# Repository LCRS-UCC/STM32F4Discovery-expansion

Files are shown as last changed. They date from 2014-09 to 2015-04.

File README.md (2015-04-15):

Placa de expansión para el kit STM32F4-Discovery
================================================

Esta es una placa con el propósito de agregar muchos periféricos para poder utilizar el kit de evaluación STM32F4-Discovery.

Periféricos:

* Ethernet
* Mirco-SD
* RGB
* Potenciómetro
* puerto serie con conversor USB
* VGA
* 4 pulsadores 
* 8 leds

placa

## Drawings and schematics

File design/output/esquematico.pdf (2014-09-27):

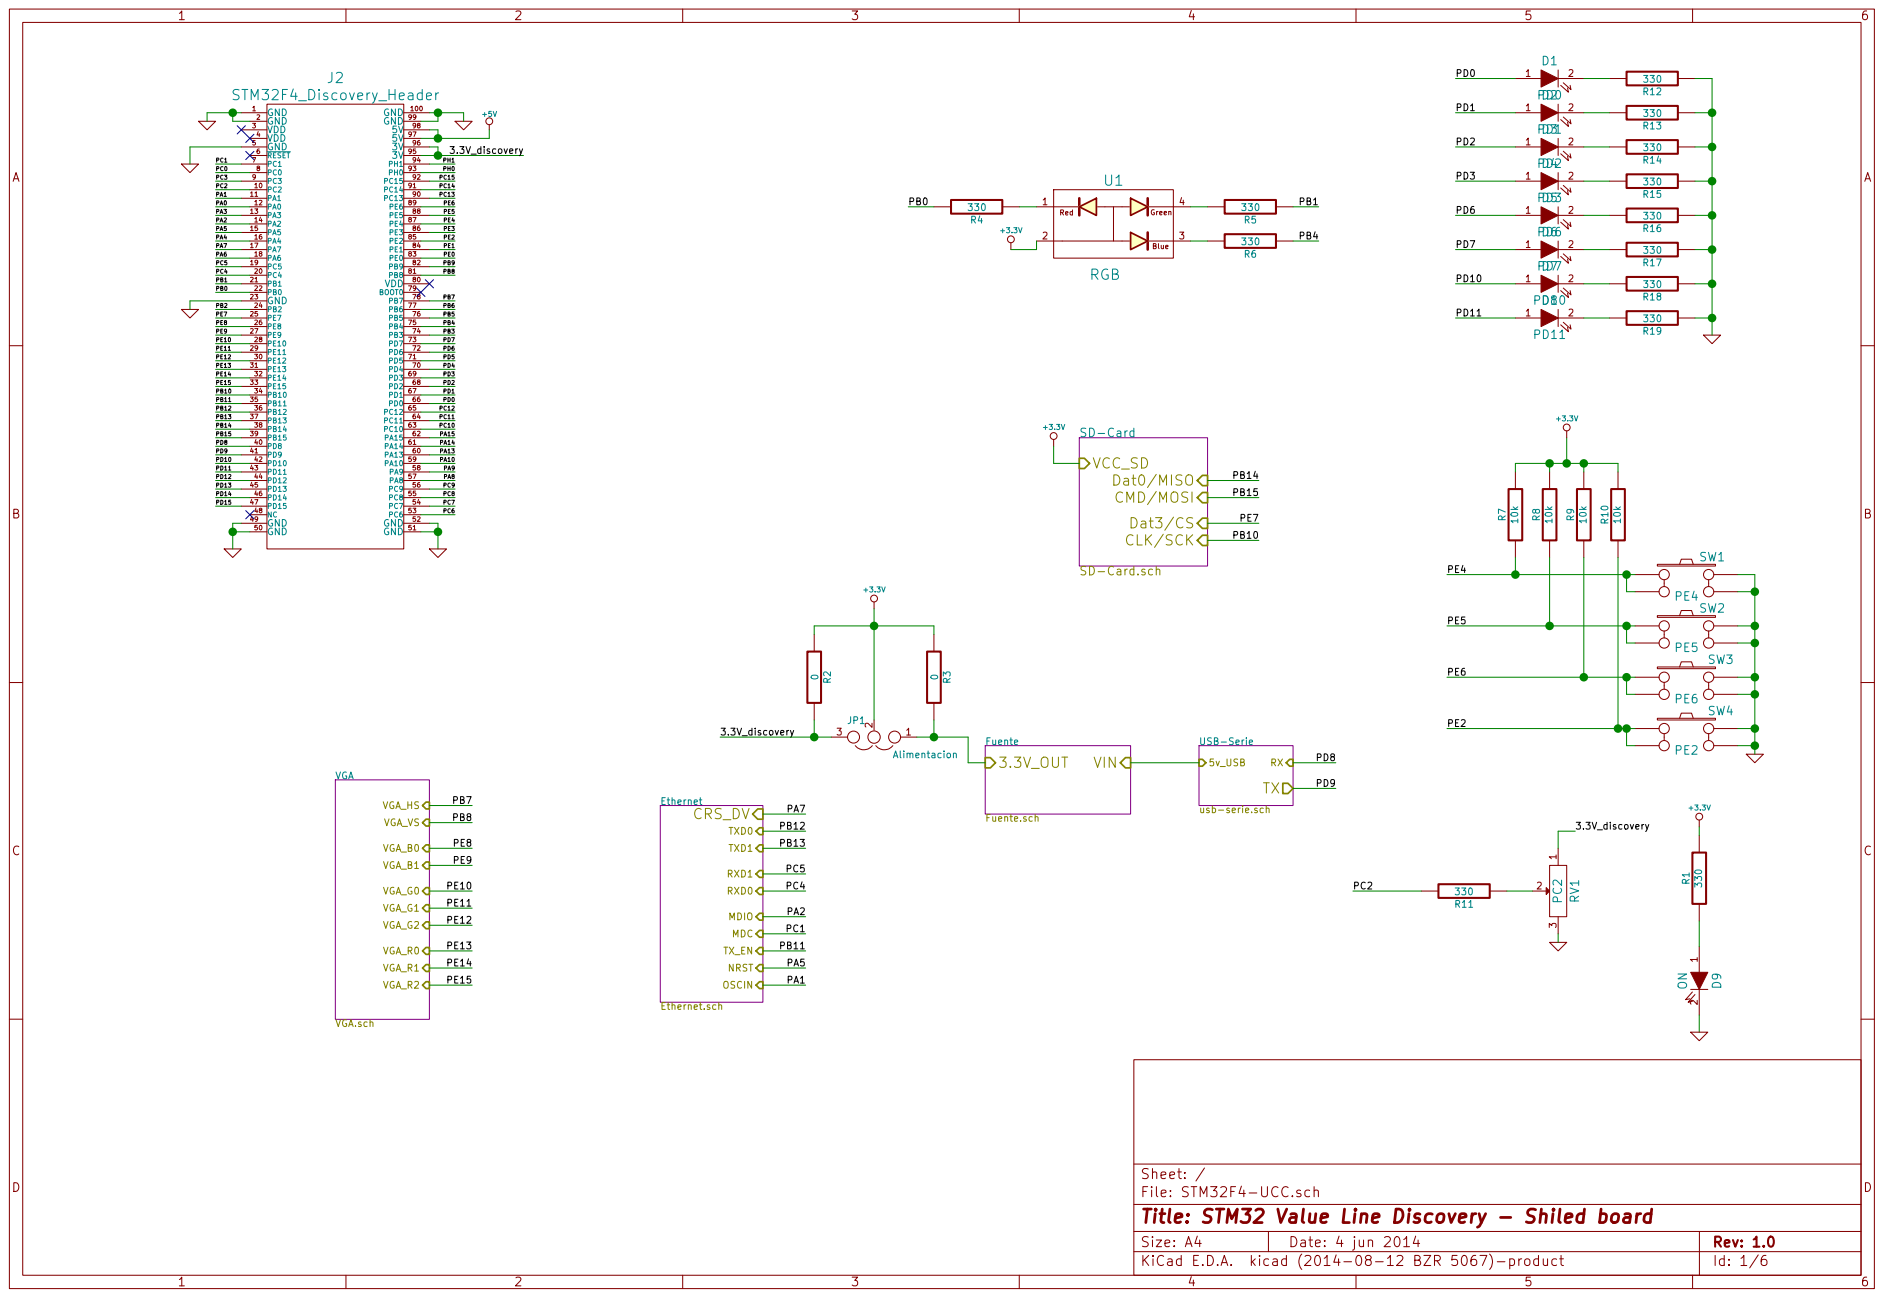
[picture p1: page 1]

Id: 1/6 Title: STM32 Value Line Discovery - Shiled board

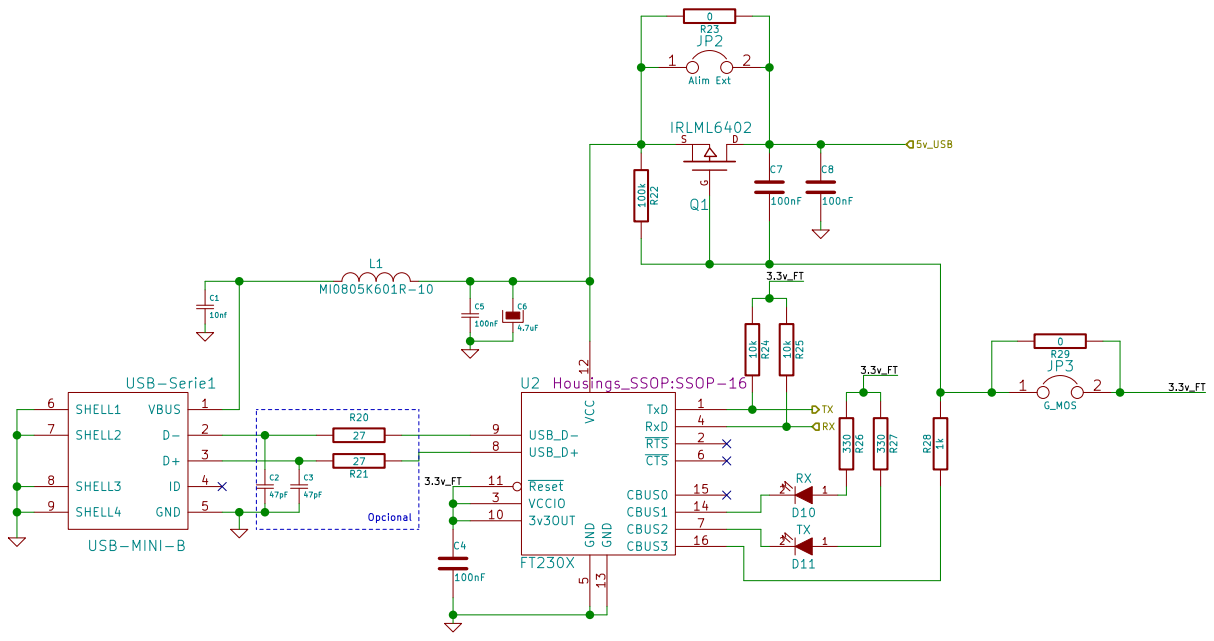
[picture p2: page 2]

Id: 2/6 Title: File: usb-serie.sch Sheet: /USB-Serie/

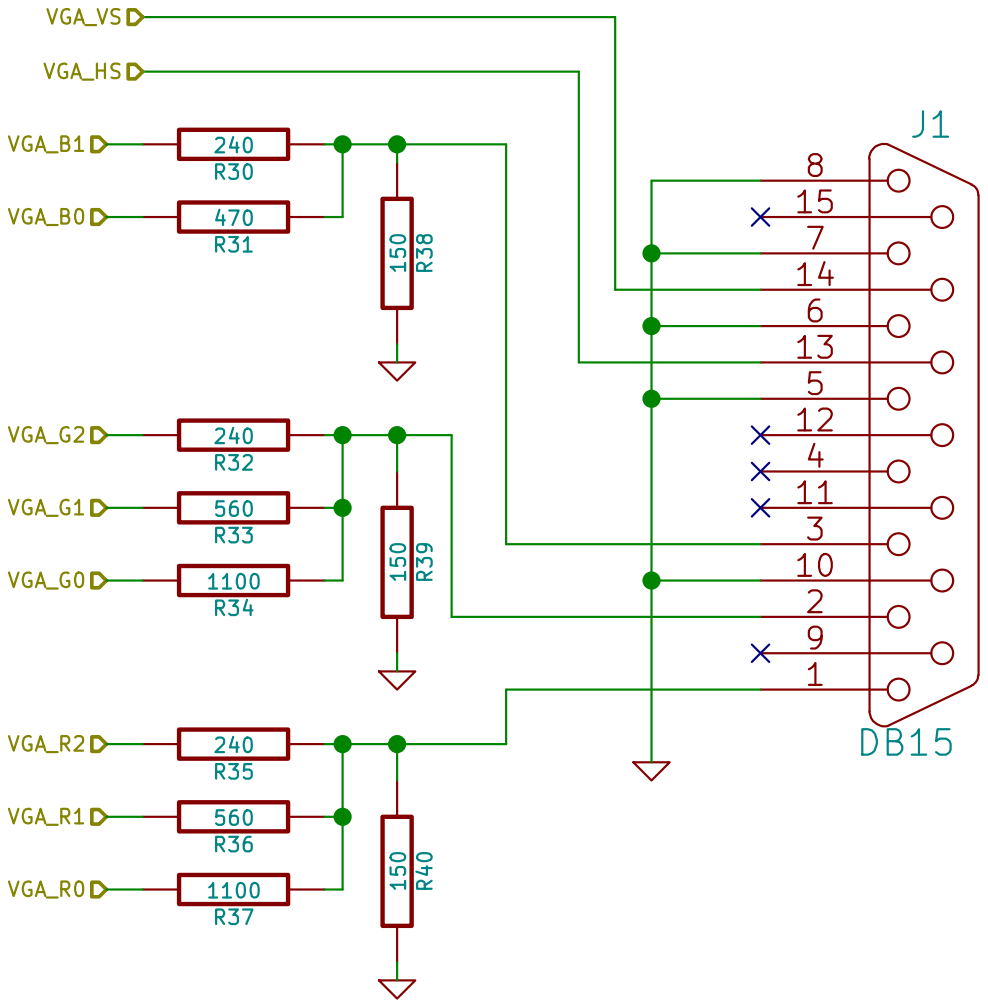
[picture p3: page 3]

Id: 3/6 Title: File: VGA.sch Sheet: /VGA/ 123456789

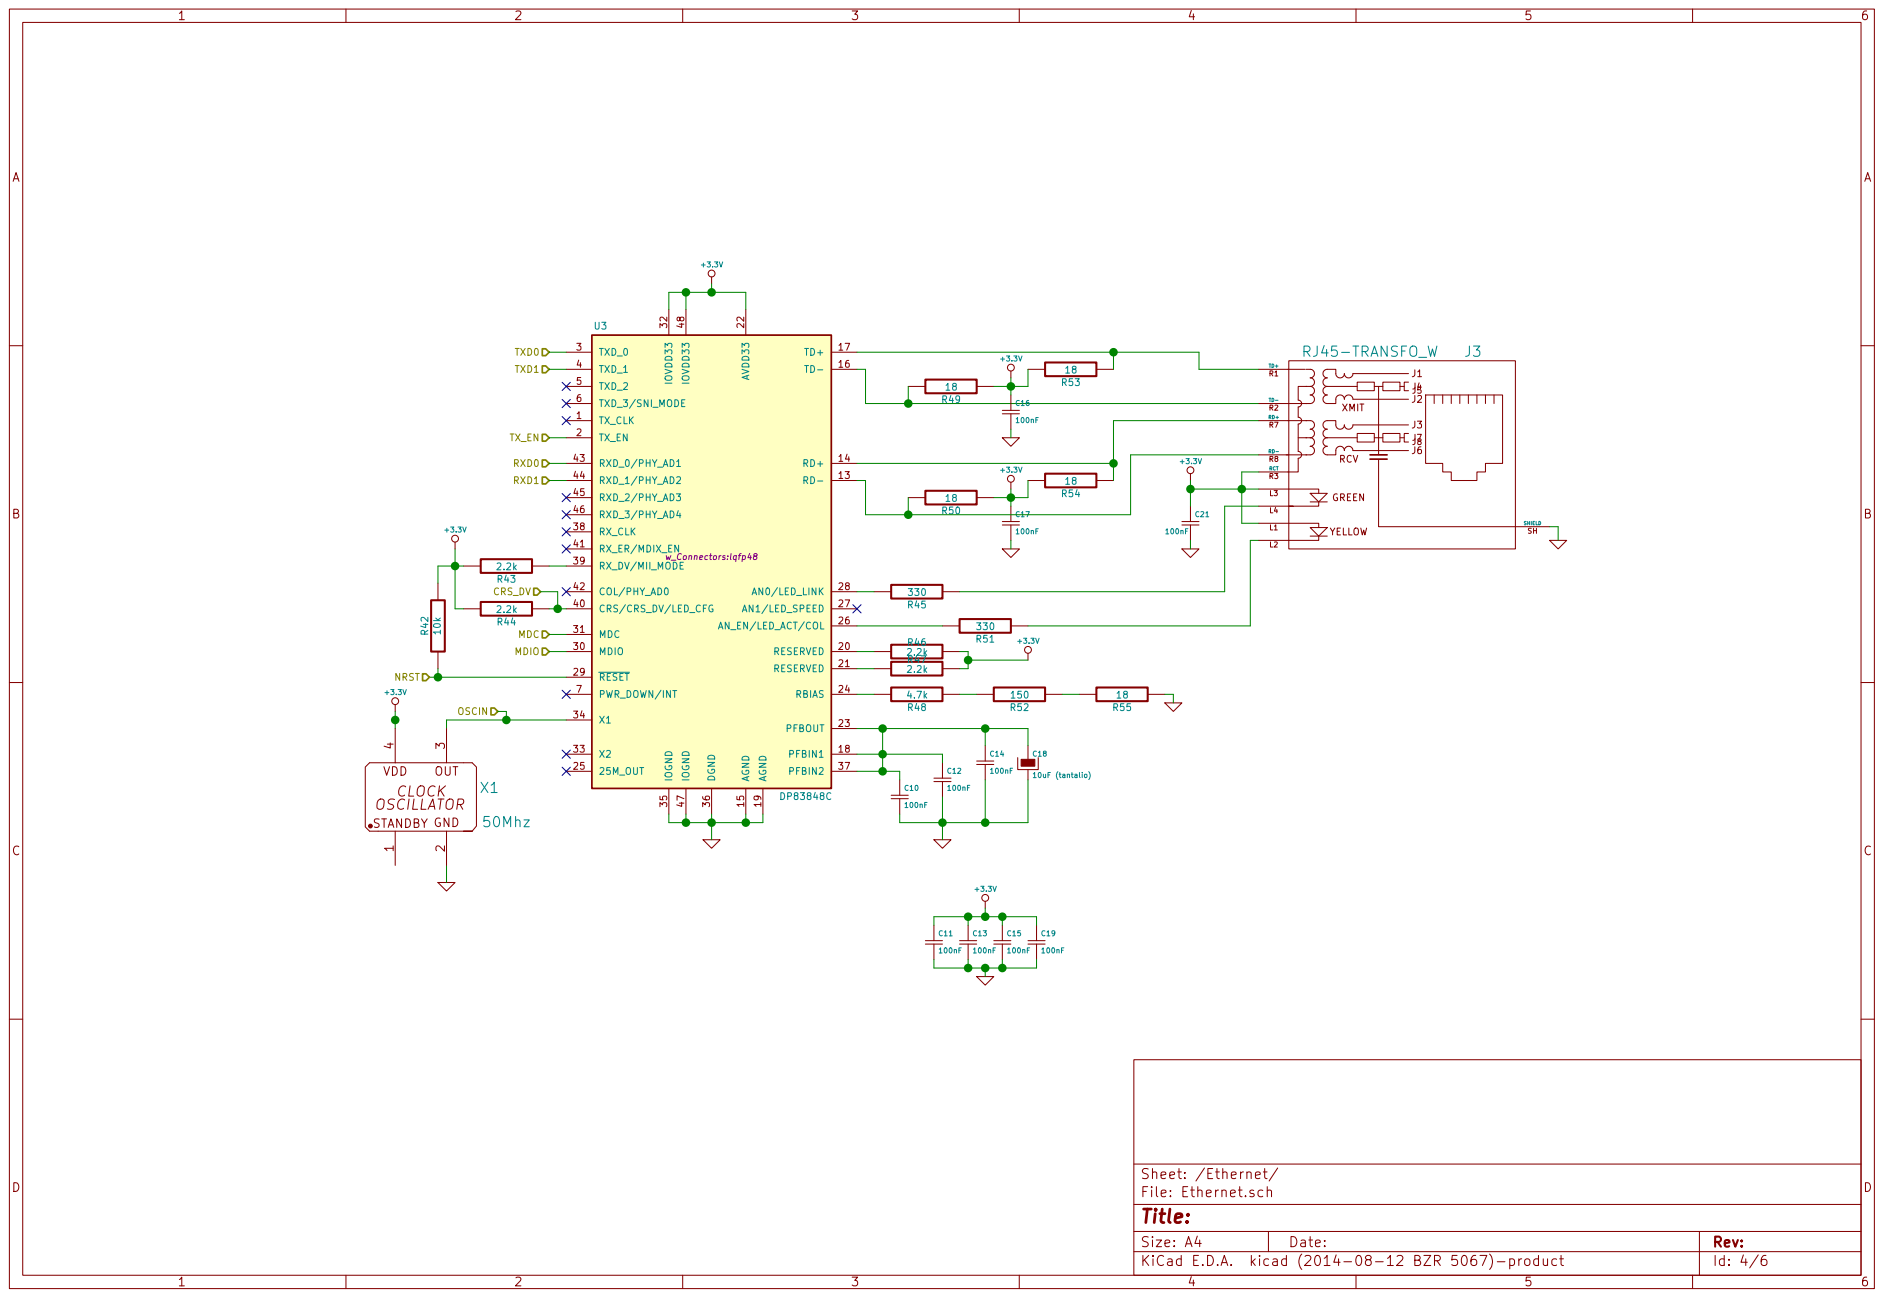
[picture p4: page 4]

Id: 4/6 Title: File: Ethernet.sch Sheet: /Ethernet/

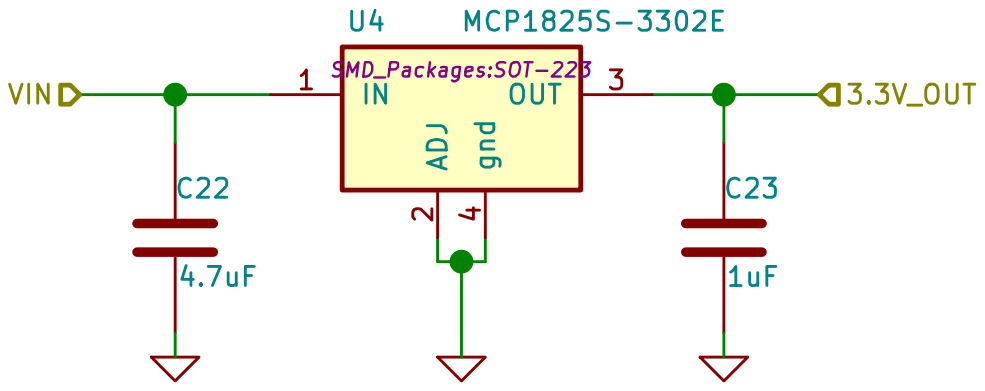
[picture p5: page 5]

Id: 5/6 Title: File: Fuente.sch Sheet: /Fuente/

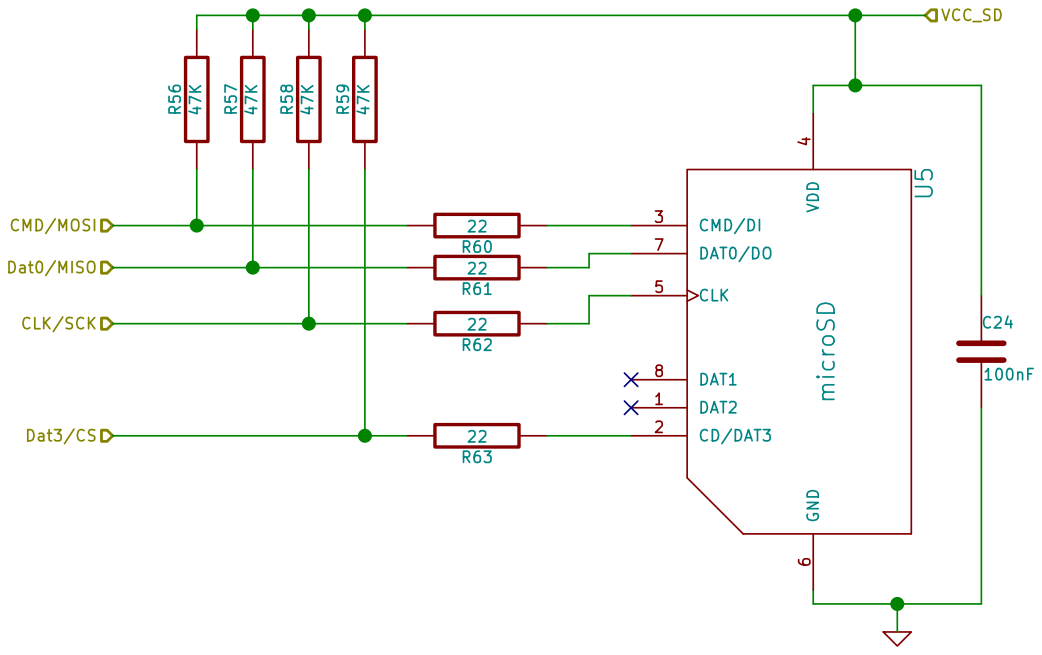
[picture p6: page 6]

CLK/SCK CMD/MOSI Dat3/CS

Id: 6/6 Title: File: SD-Card.sch Sheet: /SD-Card/

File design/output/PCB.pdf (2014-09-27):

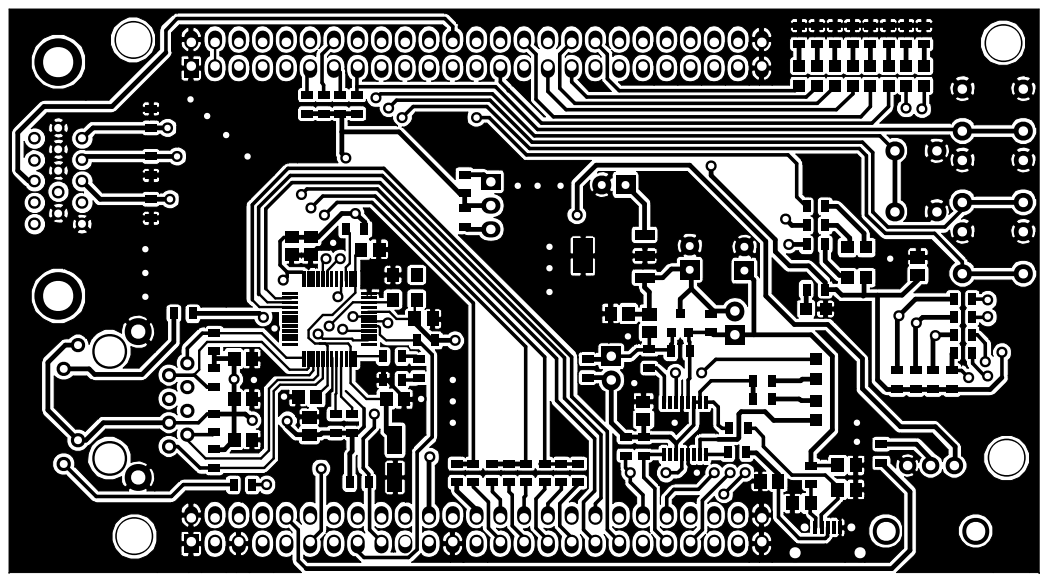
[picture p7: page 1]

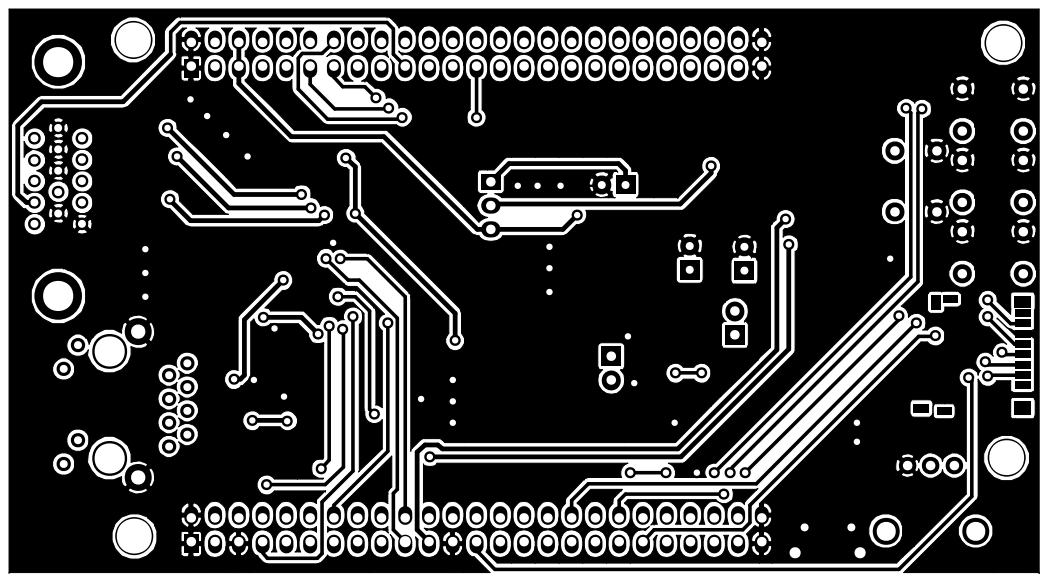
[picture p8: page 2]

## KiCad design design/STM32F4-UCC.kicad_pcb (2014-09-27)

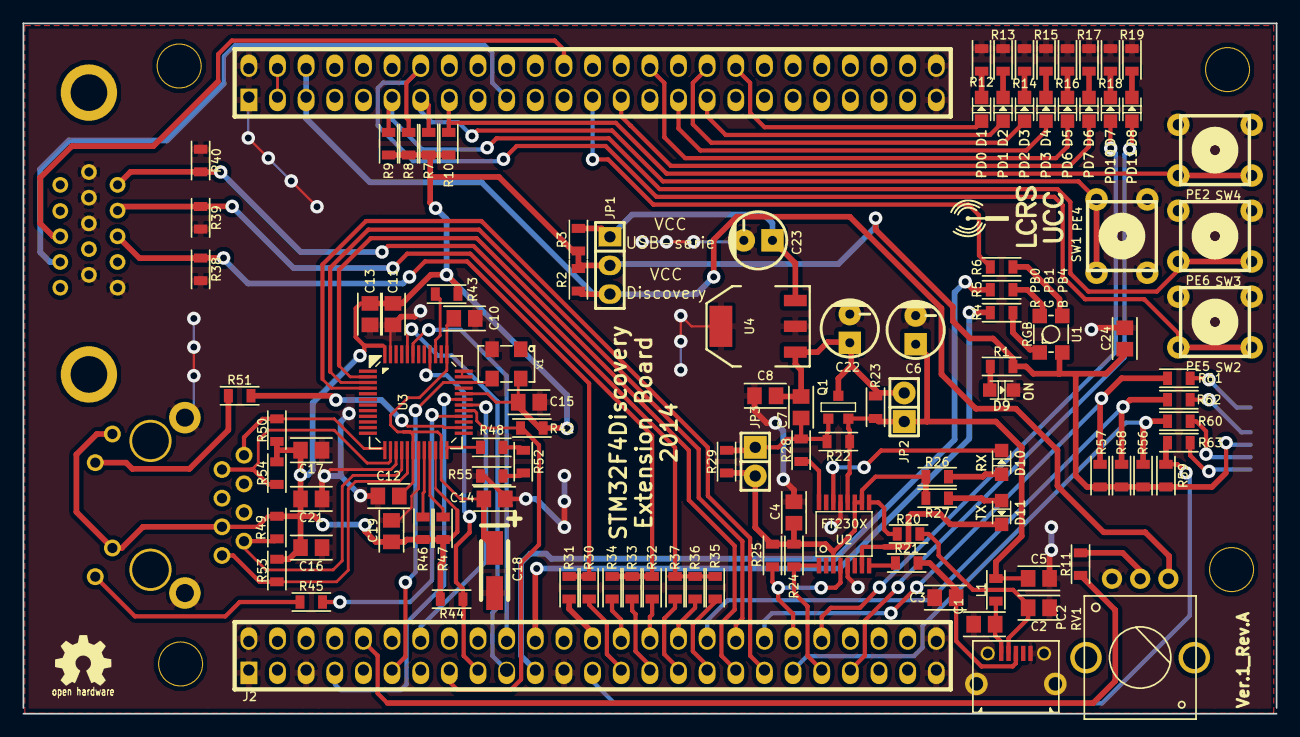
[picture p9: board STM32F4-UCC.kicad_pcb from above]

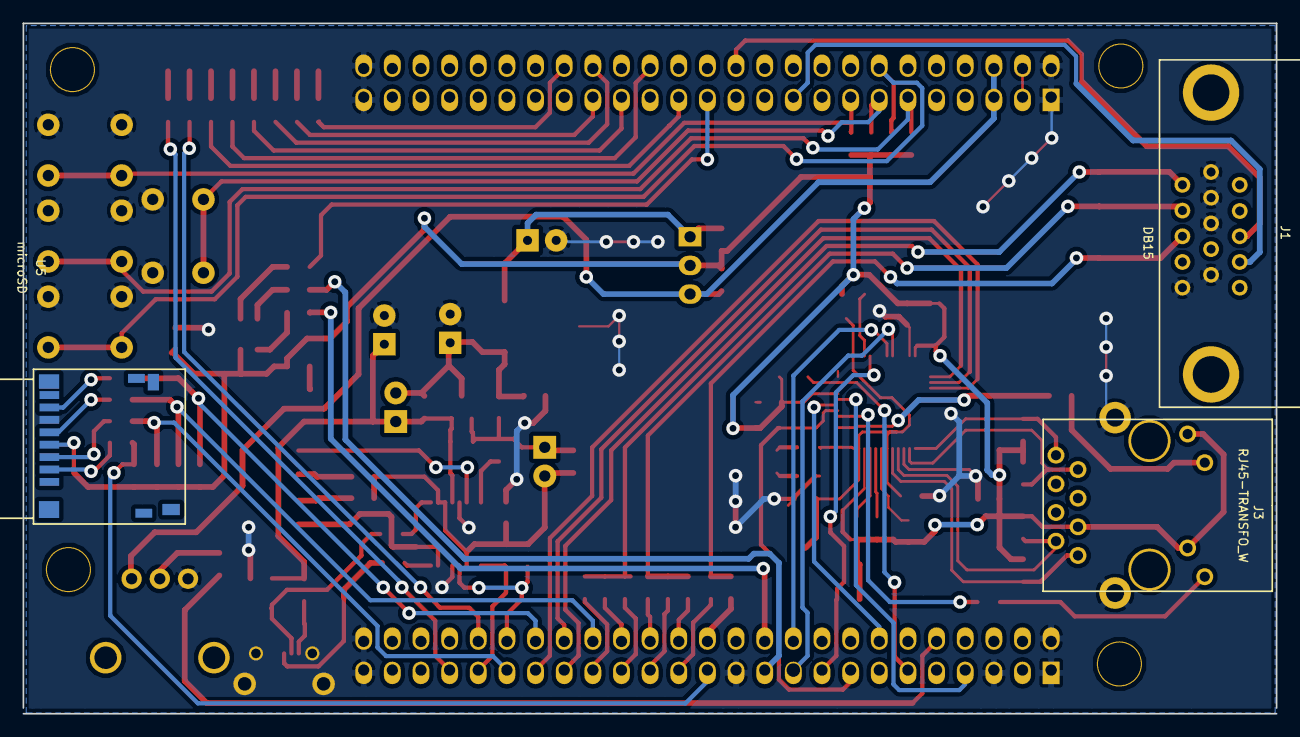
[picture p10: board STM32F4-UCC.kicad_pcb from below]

Board: 2 copper layers, 111.1 x 61.2 mm, 119 parts (3 on the bottom side), 96 nets.

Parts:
C1: 10nf; c_0805
C2, C3: 47pF; c_0805
C4, C5, C7, C8, C10, C11, C12, C13, C14, C15, C16, C17, C19, C21, C24: 100nF; c_0805
C6, C22: 4.7uF; Capacitor5x11RM2.5
C18: 10uF (tantalio); TantalC_SizeA_EIA-3216_HandSoldering
C23: 1uF; Capacitor5x11RM2.5
D1: PD0; Led_0805
D2: PD1; Led_0805
D3: PD2; Led_0805
D4: PD3; Led_0805
D5: PD6; Led_0805
D6: PD7; Led_0805
D7: PD10; Led_0805
D8: PD11; Led_0805
D9: ON; Led_0805
D10: RX; Led_0805
D11: TX; Led_0805
J1: DB15; DB_15F-VGA
J2: STM32F4_Discovery_Header; stm32f4_discovery_header
J3: RJ45-TRANSFO_W; RJ45
JP1: Alimentacion; Pin_Header_Straight_1x03
JP2: Alim Ext; Pin_Header_Straight_1x02
JP3: G_MOS; Pin_Header_Straight_1x02
L1: MI0805K601R-10; R_0805
MH: MountingHole_3-5mm_RevA_Date21Jun2010; MountingHole_3-5mm
MH#2, MH#3, MH#4: MountingHole_3-5mm_RevA_Date21Jun2010; MountingHole_3-5mm
Q1: IRLML6402; SOT-23-GDS
R1, R4, R5, R6, R11, R12, R13, R14, R15, R16, R17, R18, R19, R26, R27, R45, R51: 330; R_0805
R2, R3, R23, R29: 0; R_0805
R7, R8, R9, R10, R24, R25, R42: 10k; R_0805
R20, R21: 27; R_0805
R22: 100k; R_0805
R28: 1k; R_0805
R30, R32, R35: 240; R_0805
R31: 470; R_0805
R33, R36: 560; R_0805
R34, R37: 1100; R_0805
R38, R39, R40, R52: 150; R_0805
R43, R44, R46, R47: 2.2k; R_0805
R48: 4.7k; R_0805
R49, R50, R53, R54, R55: 18; R_0805
R56, R57, R58, R59: 47K; R_0805
R60, R61, R62, R63: 22; R_0805
RV1: PC2; POTE
SW1: PE4; PCB_PUSH
SW2: PE5; PCB_PUSH
SW3: PE6; PCB_PUSH
SW4: PE2; PCB_PUSH
U1: RGB; PLCC4
U2: FT230X; SSOP-16
U3: DP83848C; lqfp48
U4: MCP1825S-3302E; SOT-223
U5: microSD
USB-Serie1: USB-MINI-B; Micro_USB_type_B
X1: 50Mhz; crystal_fa128

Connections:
+3.3V: C11.1, C13.1, C15.1, C16.1, C17.1, C19.1, C21.1, C24.1, J3.L1, J3.L3, J3.R3, JP1.2, R1.2, R2.1, R3.1, R7.2, R8.2, R9.2, R10.2, R42.2, R43.2, R44.2, R46.1, R47.1, R49.1, R50.1, R53.2, R54.2, R56.2, R57.2, R58.2, R59.2, U1.2, U3.22, U3.32, U3.48, U5.4, X1.4
+5V: J2.97, J2.98
/3.3V_discovery: J2.95, J2.96, JP1.3, R2.2, RV1.1
/Ethernet/CRS_DV: J2.17, R44.1, U3.40
/Ethernet/MDC: J2.7, U3.31
/Ethernet/MDIO: J2.14, U3.30
/Ethernet/NRST: J2.15, R42.1, U3.29
/Ethernet/OSCIN: J2.11, U3.34, X1.3
/Ethernet/RXD0: J2.20, U3.43
/Ethernet/RXD1: J2.19, U3.44
/Ethernet/TXD0: J2.36, U3.3
/Ethernet/TXD1: J2.37, U3.4
/Ethernet/TX_EN: J2.35, U3.2
/Fuente/3.3V_OUT: C23.1, JP1.1, R3.2, U4.3
/PB0: J2.22, R4.2
/PB1: J2.21, R5.1
/PB4: J2.75, R6.1
/PC2: J2.10, R11.1
/PD0: D1.1, J2.66
/PD1: D2.1, J2.67
/PD2: D3.1, J2.68
/PD3: D4.1, J2.69
/PD6: D5.1, J2.72
/PD7: D6.1, J2.73
/PD10: D7.1, J2.42
/PD11: D8.1, J2.43
/PE2: J2.85, R10.1, SW4.1, SW4.3
/PE4: J2.87, R7.1, SW1.1, SW1.3
/PE5: J2.88, R8.1, SW2.1, SW2.3
/PE6: J2.89, R9.1, SW3.1, SW3.3
/SD-Card/CLK/SCK: J2.34, R58.1, R62.2
/SD-Card/CMD/MOSI: J2.39, R56.1, R60.2
/SD-Card/Dat0/MISO: J2.38, R57.1, R61.2
/SD-Card/Dat3/CS: J2.25, R59.1, R63.2
/USB-Serie/3.3v_FT: C4.1, JP3.2, R24.1, R25.1, R26.1, R27.1, R29.1, U2.3, U2.10, U2.11
/USB-Serie/5v_USB: C7.1, C8.1, C22.1, JP2.2, Q1.D, R23.1, U4.1
/USB-Serie/RX: J2.40, R25.2, U2.4
/USB-Serie/TX: J2.41, R24.2, U2.1
/VGA/VGA_B0: J2.26, R31.2
/VGA/VGA_B1: J2.27, R30.2
/VGA/VGA_G0: J2.28, R34.2
/VGA/VGA_G1: J2.29, R33.2
/VGA/VGA_G2: J2.30, R32.2
/VGA/VGA_HS: J1.13, J2.78
/VGA/VGA_R0: J2.31, R37.2
/VGA/VGA_R1: J2.32, R36.2
/VGA/VGA_R2: J2.33, R35.2
/VGA/VGA_VS: J1.14, J2.81
GND: C1.2, C2.2, C3.2, C4.2, C5.2, C6.2, C8.2, C10.2, C11.2, C12.2, C13.2, C14.2, C15.2, C16.2, C17.2, C18.2, C19.2, C21.2, C22.2, C23.2, C24.2, D9.2, J1.5, J1.6, J1.7, J1.8, J1.10, J2.1, J2.2, J2.5, J2.23, J2.49, J2.50, J2.51, J2.52, J2.99, J2.100, J3.SH, R12.1, R13.1, R14.1, R15.1, R16.1, R17.1, R18.1, R19.1, R38.2, R39.2, R40.2, R55.1, RV1.3, SW1.2, SW1.4, SW2.2, SW2.4, SW3.2, SW3.4, SW4.2, SW4.4, U2.5, U2.13, U3.15, U3.19, U3.35, U3.36, U3.47, U4.2, U4.4, U5.6, USB-Serie1.5, USB-Serie1.6, USB-Serie1.7, USB-Serie1.8, USB-Serie1.9, X1.2
unnamed: C1.1, L1.1, USB-Serie1.1
unnamed: C2.1, R20.2, USB-Serie1.2
unnamed: C3.1, R21.2, USB-Serie1.3
unnamed: C5.1, C6.1, JP2.1, L1.2, Q1.S, R22.1, R23.2, U2.12
unnamed: C7.2, JP3.1, Q1.G, R22.2, R28.2, R29.2
unnamed: C10.1, C12.1, C14.1, C18.1, U3.18, U3.23, U3.37
unnamed: D1.2, R12.2
unnamed: D2.2, R13.2
unnamed: D3.2, R14.2
unnamed: D4.2, R15.2
unnamed: D5.2, R16.2
unnamed: D6.2, R17.2
unnamed: D7.2, R18.2
unnamed: D8.2, R19.2
unnamed: D9.1, R1.1
unnamed: D10.1, R26.2
unnamed: D10.2, U2.14
unnamed: D11.1, R27.2
unnamed: D11.2, U2.7
unnamed: J1.1, R35.1, R36.1, R37.1, R40.1
unnamed: J1.2, R32.1, R33.1, R34.1, R39.1
unnamed: J1.3, R30.1, R31.1, R38.1
unnamed: J3.L2, R51.1
unnamed: J3.L4, R45.1
unnamed: J3.R1, R53.1, U3.17
unnamed: J3.R2, R49.2, U3.16
unnamed: J3.R7, R54.1, U3.14
unnamed: J3.R8, R50.2, U3.13
unnamed: R4.1, U1.1
unnamed: R5.2, U1.4
unnamed: R6.2, U1.3
unnamed: R11.2, RV1.2
unnamed: R20.1, U2.9
unnamed: R21.1, U2.8
unnamed: R28.1, U2.16
unnamed: R43.1, U3.39
unnamed: R45.2, U3.28
unnamed: R46.2, U3.20
unnamed: R47.2, U3.21
unnamed: R48.1, R52.2
unnamed: R48.2, U3.24
unnamed: R51.2, U3.26
unnamed: R52.1, R55.2
unnamed: R60.1, U5.3
unnamed: R61.1, U5.7
unnamed: R62.1, U5.5
unnamed: R63.1, U5.2

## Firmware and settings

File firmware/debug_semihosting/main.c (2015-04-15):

#include <stdint.h>
#include "bsp/bsp.h"
#include <stdio.h>
/**
 * @brief Delay por software
 *
 * @param nCount Numero de ciclos del delay
 */
void Delay(volatile uint32_t nCount);

/**
 * @brief Se encarga de prender un led y apagarlo luego de un tiempo
 *
 * @param led    Numero de led a pulsar
 * @param tiempo Numero de ciclos del delay entre prendido y apagado
 */
void pulsoLed(uint8_t led, uint32_t tiempo);

/**
 * @brief Aplicacion principal
 */
int main(void) {
	bsp_init();
	char console_in;
	int	counter;
	counter=0;
	while (1) {
		bsp_delayMs(1000);
		led_toggle(1);
		counter = (counter +1)% 100;
		printf("counter:%03d\n\r",counter);
		printf("Presione una tecla y enter:\n\r");
		console_in=SH_GetChar();
		printf("Se presiono:0x%02X\n\r",console_in);
	}
}


void pulsoLed(uint8_t led, uint32_t tiempo){
	led_on(led);
	Delay(tiempo);
	led_off(led);
}

void Delay(volatile uint32_t nCount) {
	while (nCount--) {
	}
}


void APP_ISR_sw(void){
	//led_toggle(0);
	//led_toggle(1);
	led_toggle(2);
	led_toggle(3);
}

void APP_ISR_1ms(void){
	static uint16_t count_1s = 1000;
	count_1s--;
	if (!count_1s) {
		led_toggle(0);
		count_1s = 1000;
	}
}

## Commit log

2014-06-05 Primeras lineas del esquematico y la placa
    [STM32F4-UCC.kicad_pcb, STM32F4-UCC.sch, VGA.sch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]
2014-06-08 Agregado modulo Ethernet
    [Ethernet.sch]
2014-06-09 added some resistors values
    [STM32F4-UCC.sch, VGA.sch, usb-serie.sch]
2014-07-28 Se agrego alimentacion por USB-Serie, falta fuente
    [Ethernet.sch, Fuente.sch, STM32F4-UCC.sch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]
2014-08-05 Se agrego SD, se colocaron pins en varios modulos, se corrigio orden del VGA
    [Ethernet.sch, Fuente.sch, SD-Card.sch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]
2014-08-09 Arreglada la distribucion de pines
    [Ethernet.sch, SD-Card.sch, STM32F4-UCC.sch]
2014-08-14 Terminado el esquematico, iniciado el PCB
    [Ethernet.sch, Fuente.sch, SD-Card.sch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]
2014-08-18 Terminado el Routeo de la Placa
    [Ethernet.sch, Fuente.sch, SD-Card.sch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]
2014-08-20 Se arreglo pista a via
    [STM32F4-UCC.kicad_pcb]
2014-08-22 Se reRouteo con clearance 12 en general
    [Ethernet.sch, STM32F4-UCC.kicad_pcb]
2014-08-24 Placa terminada, serigrafia verificada, logos agregados
    [Ethernet.sch, Fuente.sch, SD-Card.sch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]
2014-08-26 Se agregan salidas de archivos en PDF y se realizan algunos cambios
    [STM32F4-UCC-B_Cu.gbl, STM32F4-UCC-B_Mask.gbs, STM32F4-UCC-B_SilkS.gbo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]
2014-08-26 Subido pdf nuevo de la placa
2014-08-26 Cambios minimos y nuevo PDF y gerbers
    [STM32F4-UCC-B_Cu.gbl, STM32F4-UCC-B_Mask.gbs, STM32F4-UCC-B_SilkS.gbo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]
2014-08-27 Placa con errores solucionados
    [STM32F4-UCC-B_Cu.gbl, STM32F4-UCC-B_Mask.gbs, STM32F4-UCC-Edge_Cuts.gbr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]
2014-09-27 Ultimos cambios realizados antes de enviar la placa.
    [STM32F4-UCC-B_Cu.gbl, STM32F4-UCC-B_Mask.gbs, STM32F4-UCC-Edge_Cuts.gbr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]
2014-09-27 Se acomodaron los archivos para que quede mas prolijo
    [STM32F4-UCC.kicad_pcb]
2014-09-27 Se agregaron carpeta de footprint y salida en pdf y gerbers
    [STM32F4-UCC-B_Cu.gbl, STM32F4-UCC-B_Mask.gbs, STM32F4-UCC-Edge_Cuts.gbr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]
2014-10-01 Se agrego la funcionalidad semihosting al proyecto TP4 para poder recibir y transmitir datos por medio de jtag y una consola
2015-04-15 * License added * renamed some directories * removed firmware folder
    [Ethernet.sch, Fuente.sch, SD-Card.sch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]
2015-04-15 * Agregado Readme para github
